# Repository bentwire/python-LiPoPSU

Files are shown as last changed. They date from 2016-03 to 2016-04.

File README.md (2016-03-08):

# python-LiPoPSU
Python drivers and sundry for my LiPo PSU design in eagle

Boards can be ordered from OSH Park

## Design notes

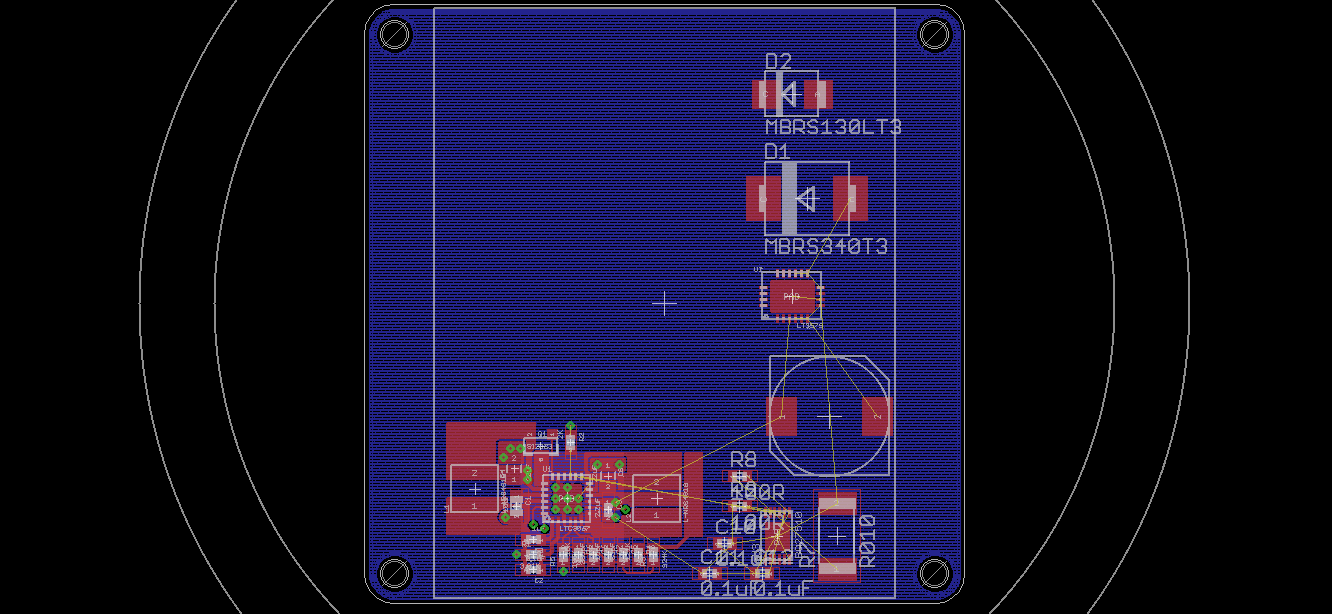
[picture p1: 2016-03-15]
eagle/LiPo-PSU/lipo.png

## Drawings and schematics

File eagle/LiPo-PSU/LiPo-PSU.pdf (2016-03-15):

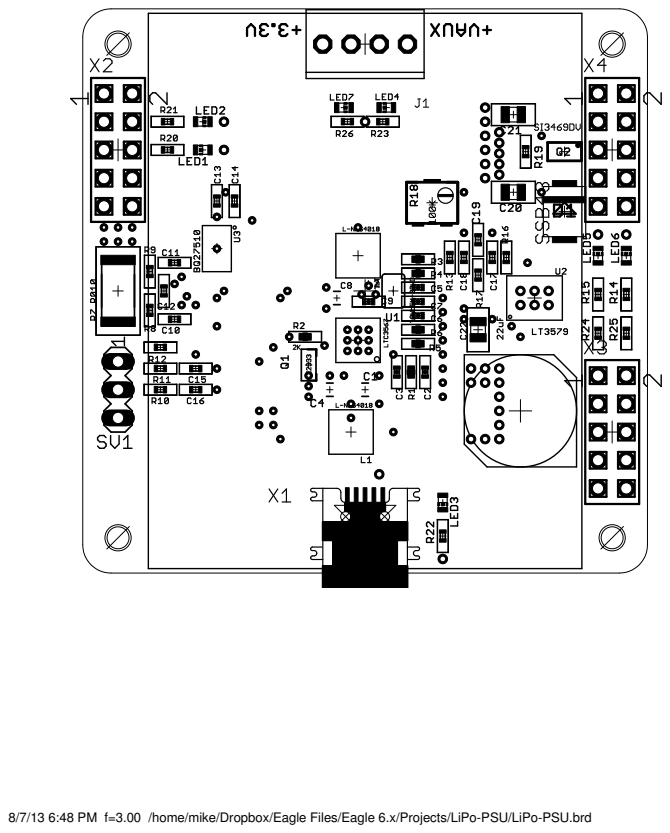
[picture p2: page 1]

8/7/13 6:48 PM f=3.00 /home/mike/Dropbox/Eagle Files/Eagle 6.x/Projects/LiPo-PSU/LiPo-PSU.brd

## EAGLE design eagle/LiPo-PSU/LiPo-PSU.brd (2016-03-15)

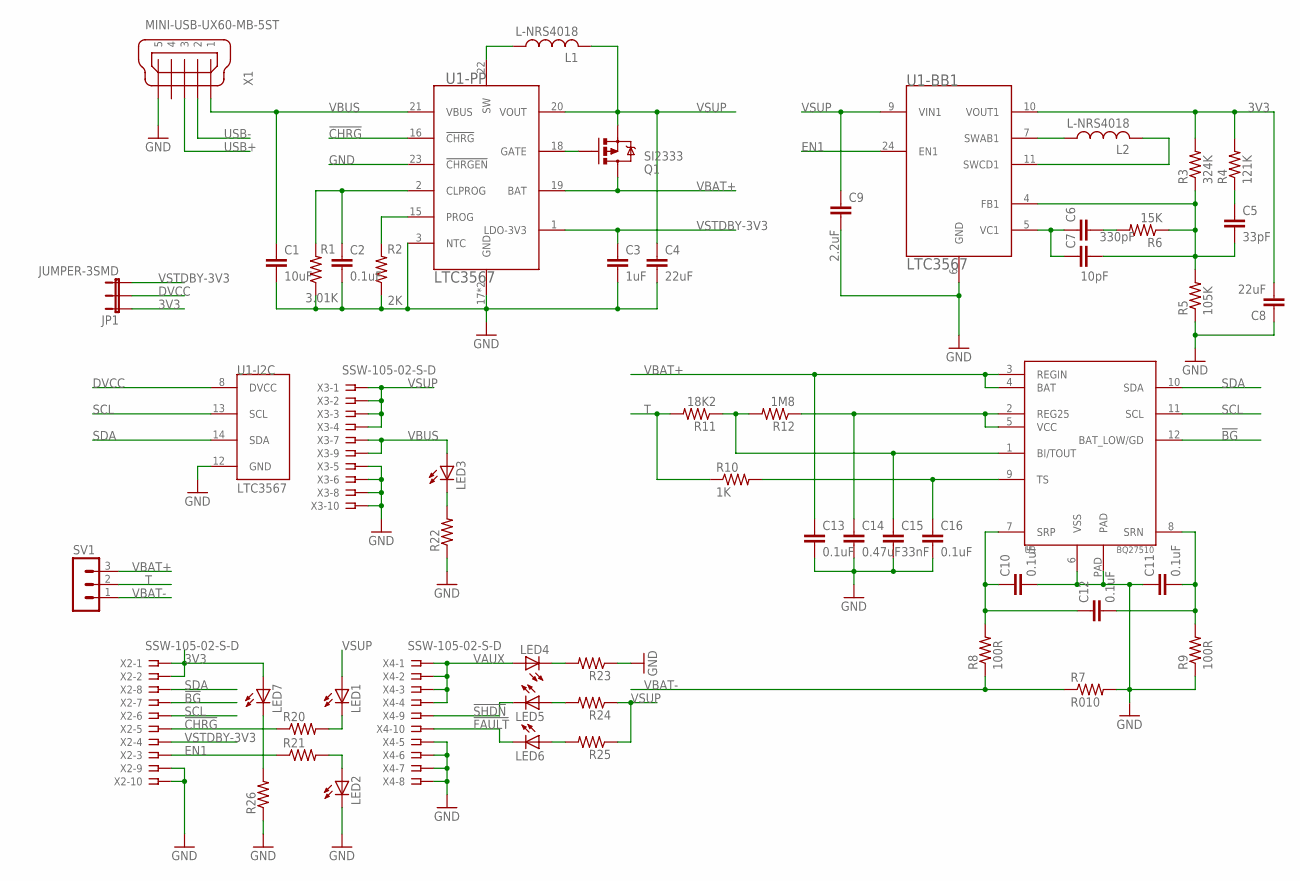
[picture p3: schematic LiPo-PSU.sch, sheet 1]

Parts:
C1: 10uF; 0805
C2: 0.1uF; 0402-CAP
C3: 1uF; 0402-CAP
C4, C8: 22uF; 0805
C5: 33pF; 0402-CAP
C6: 330pF; 0402-CAP
C7: 10pF; 0402-CAP
C9: 2.2uF; 0402-CAP
C10, C11, C12, C13, C16: 0.1uF; C0402
C14: 0.47uF; C0402
C15: 33nF; C0402
JP1: JUMPER-3SMD; SJ_3
L1, L2: L-NRS4018; NR(S)401X
LED1, LED2, LED3, LED4, LED5, LED6, LED7: LEDCHIP-LED0603; CHIP-LED0603
Q1: SI2333; SOT23-3
R1: 3.01K; 0402-RES
R2: 2K; 0402-RES
R3: 324K; 0402-RES
R4: 121K; 0402-RES
R5: 105K; 0402-RES
R6: 15K; 0402-RES
R7: R010; R2512
R8, R9: 100R; R0402
R10: 1K; R0402
R11: 18K2; R0402
R12: 1M8; R0402
R20, R21, R22, R23, R24, R25, R26: R-US_R0402; R0402
SV1: MA03-1
U1: LTC3567; QFN24-4X4(UF)
U3: BQ27510; DRZ(S-PDSO-N12)
X1: MINI-USB-UX60-MB-5ST; UX60-MB-5ST
X2, X3, X4: SSW-105-02-S-D

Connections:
3V3: C8.2, JP1.1, LED7.A, R3.2, R4.2, U1.10 (VOUT1), X2.1, X2.2; also elsewhere on the board
!BG: U3.12 (BAT_LOW/GD), X2.7
!CHRG!: R20.1, U1.16 (!CHRG!), X2.5
!FAULT: LED6.C, X4.10; also elsewhere on the board
!SHDN: LED5.C, X4.9; also elsewhere on the board
DVCC: JP1.2, U1.8 (DVCC)
EN1: R21.1, U1.24 (EN1), X2.3
GND: C1.2, C2.2, C3.2, C4.2, C8.1, C9.2, C10.2, C11.1, C13.2, C14.2, C15.2, C16.2, LED2.C, R1.1, R2.1, R5.1, R7.2, R9.1, R22.1, R23.1, R26.1, U1.3 (NTC), U1.6 (GND), U1.12 (GND), U1.17 (GND), U1.23 (!CHRGEN!), U1.PAD (GND), U3.6 (VSS), U3.PAD, X1.5, X2.9, X2.10, X3.5, X3.6, X3.8, X3.10, X4.5, X4.6, X4.7, X4.8; also elsewhere on the board
unnamed: L1.1, U1.22 (SW)
unnamed: C5.2, C7.2, R3.1, R5.2, R6.1, U1.4 (FB1)
unnamed: Q1.1 (G), U1.18 (GATE)
unnamed: L2.1, U1.7 (SWAB1)
unnamed: L2.2, U1.11 (SWCD1)
unnamed: C5.1, R4.1
unnamed: C15.1, R11.1, R12.2, U3.1 (BI/TOUT)
unnamed: C6.2, R6.2
unnamed: C6.1, C7.1, U1.5 (VC1)
unnamed: C2.1, R1.2, U1.2 (CLPROG)
unnamed: R2.2, U1.15 (PROG)
unnamed: LED1.C, R20.2
unnamed: C14.1, R12.1, U3.2 (REG25), U3.5 (VCC)
unnamed: LED2.A, R21.2
unnamed: LED3.C, R22.2
unnamed: LED5.A, R24.2
unnamed: LED6.A, R25.2
unnamed: LED4.C, R23.2
unnamed: LED7.C, R26.2
SCL: U1.13 (SCL), U3.11 (SCL), X2.6
SDA: U1.14 (SDA), U3.10 (SDA), X2.8
SRN: C11.2, C12.2, R9.2, U3.8 (SRN)
SRP: C10.1, C12.1, R8.2, U3.7 (SRP)
T: R10.1, R11.2, SV1.2
TIN: C16.1, R10.2, U3.9 (TS)
USB+: X1.3
USB-: X1.2
VAUX: LED4.A, X4.1, X4.2, X4.3, X4.4; also elsewhere on the board
VBAT+: C13.1, Q1.3 (D), SV1.3, U1.19 (BAT), U3.3 (REGIN), U3.4 (BAT)
VBAT-: R7.1, R8.1, SV1.1
VBUS: C1.1, LED3.A, U1.21 (VBUS), X1.1, X3.7, X3.9
VSTDBY-3V3: C3.1, JP1.3, U1.1 (LDO-3V3), X2.4
VSUP: C4.1, C9.1, L1.2, LED1.A, Q1.2 (S), R24.1, R25.1, U1.9 (VIN1), U1.20 (VOUT), X3.1, X3.2, X3.3, X3.4; also elsewhere on the board

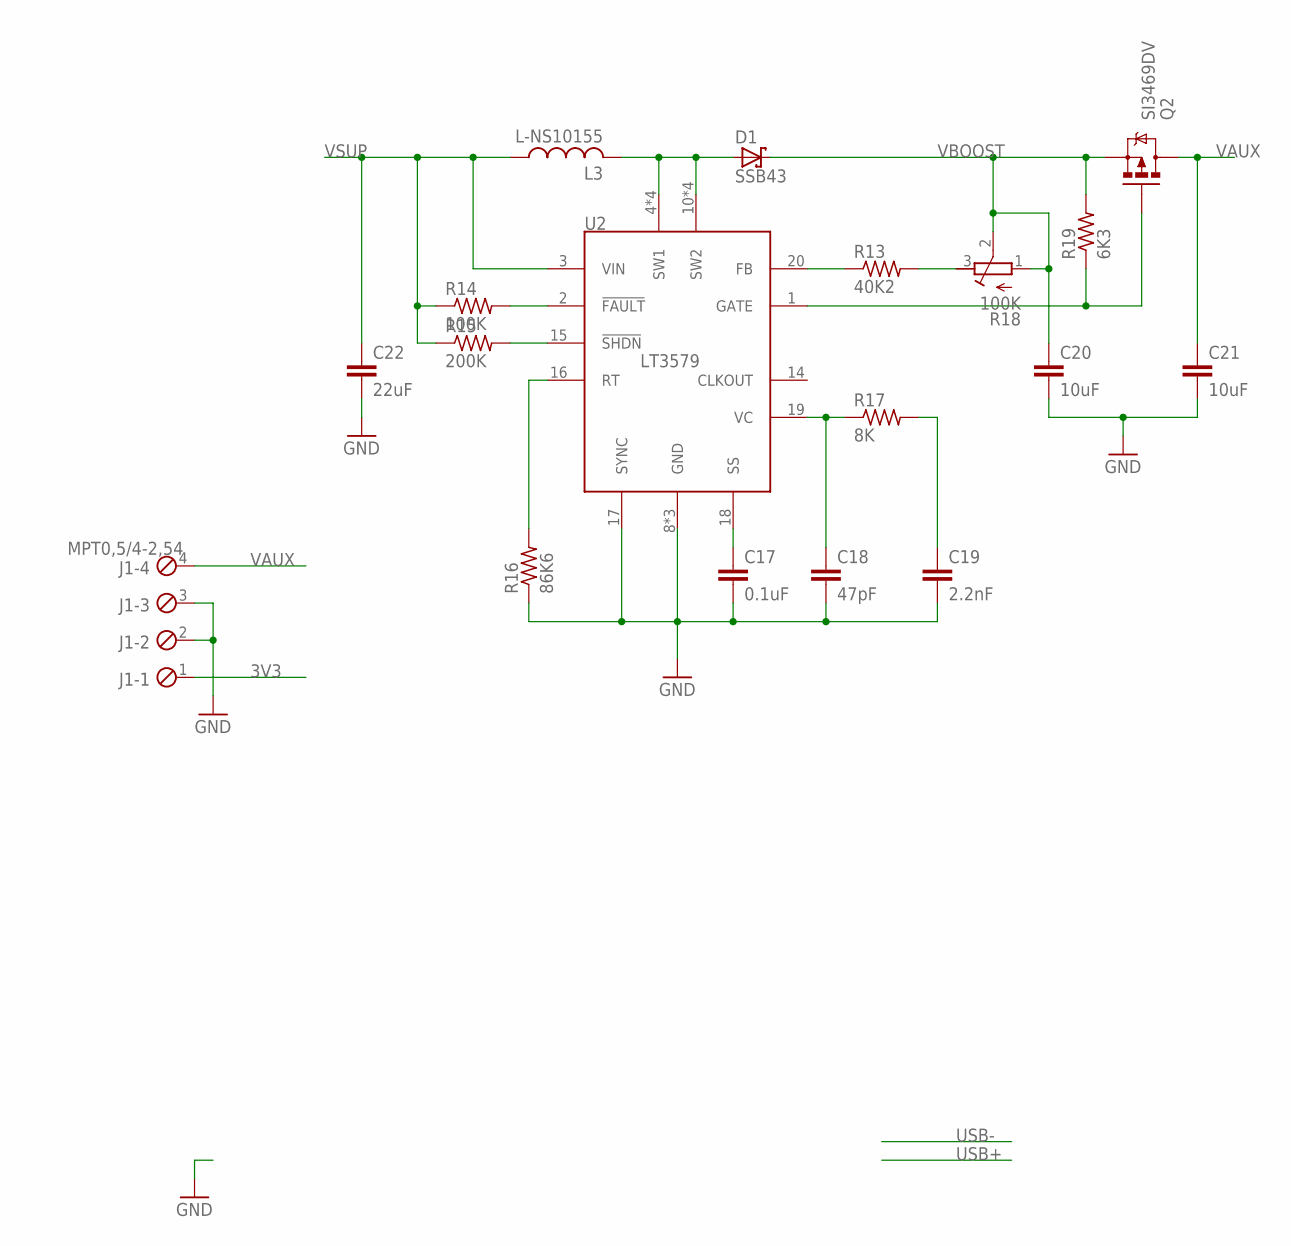
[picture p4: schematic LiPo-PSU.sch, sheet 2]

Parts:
C17: 0.1uF; C0402
C18: 47pF; C0402
C19: 2.2nF; C0402
C20, C21: 10uF; C0805
C22: 22uF; C0805
D1: SSB43; SMB
J1: MPT0,5/4-2,54
L3: L-NS10155; NS10155
Q2: SI3469DV; TSOP-6
R13: 40K2; R0402
R14: 100K; R0402
R15: 200K; R0402
R16: 86K6; R0402
R17: 8K; R0402
R18: 100K; RTRIM3214W
R19: 6K3; R0402
U2: LT3579; QFN20-4X5(UFD)

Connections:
3V3: J1.1; also elsewhere on the board
!FAULT: R14.2, U2.2 (!FAULT!); also elsewhere on the board
!SHDN: R15.2, U2.15 (!SHDN!); also elsewhere on the board
BOOST-FB: R13.1, U2.20 (FB)
GATE: Q2.3 (G), R19.1, U2.1 (GATE)
GND: C17.2, C18.2, C19.2, C20.2, C21.2, C22.2, J1.2, J1.3, R16.1, U2.8 (GND), U2.9 (GND), U2.17 (SYNC), U2.PAD (GND); also elsewhere on the board
unnamed: D1.A, L3.2, U2.4 (SW1), U2.5 (SW1), U2.6 (SW1), U2.7 (SW1), U2.10 (SW2), U2.11 (SW2), U2.12 (SW2), U2.13 (SW2)
unnamed: R13.2, R18.3 (A)
unnamed: R16.2, U2.16 (RT)
unnamed: C18.1, R17.1, U2.19 (VC)
unnamed: C19.1, R17.2
unnamed: C17.1, U2.18 (SS)
VAUX: C21.1, J1.4, Q2.1 (D), Q2.2 (D), Q2.5 (D), Q2.6 (D); also elsewhere on the board
VBOOST: C20.1, D1.C, Q2.4 (S), R18.1 (E), R18.2 (S), R19.2
VSUP: C22.1, L3.1, R14.1, R15.1, U2.3 (VIN); also elsewhere on the board

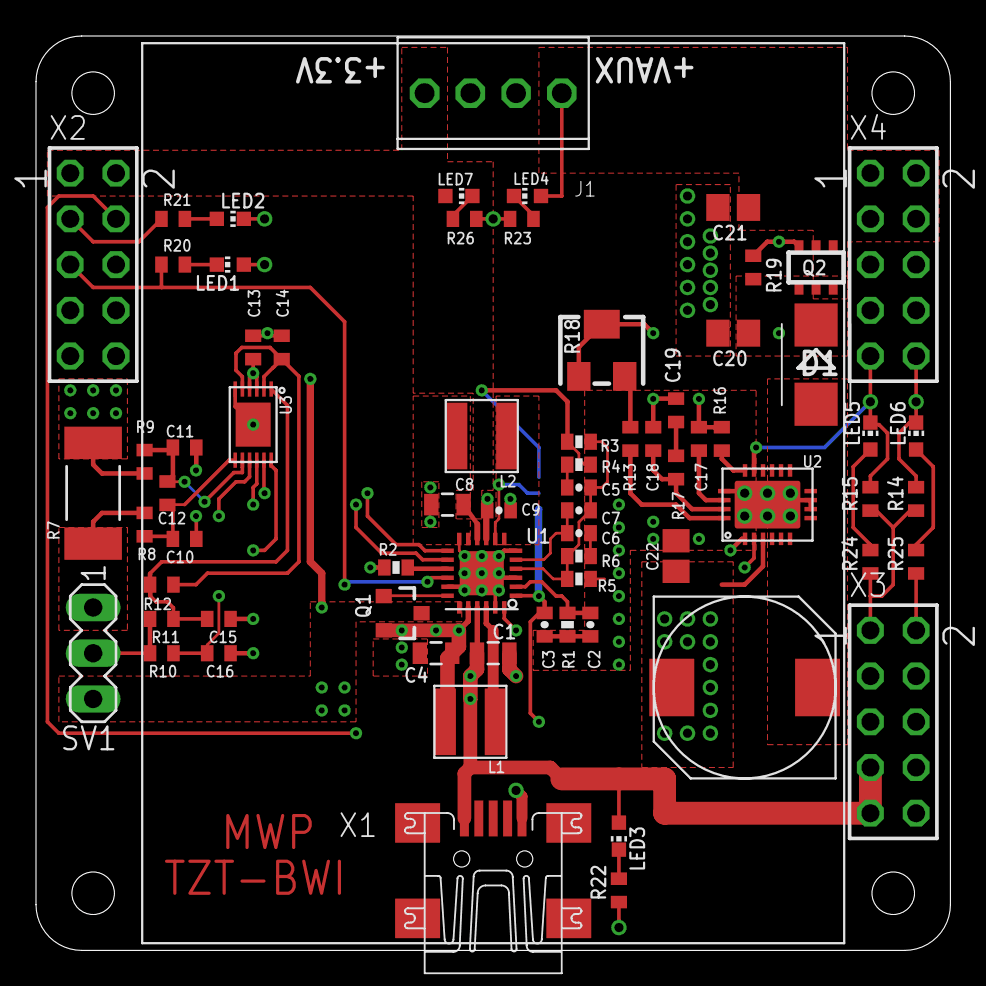
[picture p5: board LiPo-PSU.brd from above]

Board: 4 copper layers, 50.8 x 50.8 mm, 72 parts (1 on the bottom side), 48 nets.

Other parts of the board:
U$1: LP503950

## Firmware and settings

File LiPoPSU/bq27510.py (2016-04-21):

import time
import logging

log = logging.getLogger(__name__)


class bq27510(object):
    CNTL    = 0x00 # This and AR are the only R/W regs.
    AR      = 0x02
    ARTTE   = 0x04 # From here down the registers are RO.
    TEMP    = 0x06
    VOLT    = 0x08
    FLAGS   = 0x0a
    NAC     = 0x0c
    FAC     = 0x0e
    RM      = 0x10
    FCC     = 0x12
    AI      = 0x14
    TTE     = 0x16
    TTF     = 0x18
    SI      = 0x1a
    STTE    = 0x1c
    MLI     = 0x1e
    MLTTE   = 0x20
    AE      = 0x22
    AP      = 0x24
    TTECP   = 0x26
    RSVD    = 0x28
    CC      = 0x2a
    SOC     = 0x2c

    ADDRESS = 0x55

    def __init__(self, bus, retries = 5):
        self.bus     = bus
        self.retries = retries

    def readReg(self, reg):
        for retry in range(self.retries):
            try:
                return self.bus.read_word_data(bq27510.ADDRESS, reg)
            except Exception as e:
                log.error("Exception during read: %s" % (e))
                time.sleep(0.1)
        else:
            raise Exception("Too many retries on READ.")

    @property
    def Control(self):
        return self.readReg(bq27510.CNTL)

    @Control.setter
    def Control(self, val):
        return self.writeReg(bq27510.CNTL)

    @property
    def Temperature(self):
        return self.readReg(bq27510.TEMP)

    @property
    def Voltage(self):
        voltage = self.readReg(bq27510.VOLT)
        return float(voltage)/1000

    @property
    def Flags(self):
        return self.readReg(bq27510.FLAGS)

    @property
    def NominalAvailableCapacity(self):
        cap = self.readReg(bq27510.NAC)
        return float(cap)/1000

    @property
    def FullAvailableCapacity(self):
        cap = self.readReg(bq27510.FAC)
        return float(cap)/1000

    @property
    def RemainingCapacity(self):
        cap = self.readReg(bq27510.RM)
        return float(cap)/1000

    @property
    def FullChargeCapacity(self):
        cap = self.readReg(bq27510.FCC)
        return float(cap)/1000

    @property
    def AverageCurrent(self):
        current = self.readReg(bq27510.AI)
        if current > 32767:
            current -= 65536
        return float(current)/1000

    @property
    def TimeToEmpty(self):
        return self.readReg(bq27510.TTE)

    @property
    def TimeToFull(self):
        return self.readReg(bq27510.TTF)

    @property
    def StandbyCurrent(self):
        i = self.readReg(bq27510.SI)
        return float(i)/1000

    @property
    def StandbyTimeToEmpty(self):
        return self.readReg(bq27510.STTE)

    @property
    def MaxLoadCurrent(self):
        i = self.readReg(bq27510.MLI)
        return float(i)/1000

    @property
    def MaxLoadTimeToEmpty(self):
        return self.readReg(bq27510.MLTTE)

    @property
    def AvailableEnergy(self):
        ae = self.readReg(bq27510.AE)
        return float(ae)/1000

    @property
    def AveragePower(self):
        ap = self.readReg(bq27510.AP)
        return float(ap)/1000

    @property
    def TTEatConstantPower(self):
        return self.readReg(bq27510.TTECP)

    @property
    def CycleCount(self):
        return self.readReg(bq27510.CC)

    @property
    def StateOfCharge(self):
        return self.readReg(bq27510.SOC)

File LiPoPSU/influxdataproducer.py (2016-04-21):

#!/usr/bin/env python

"""Generate time series data for influxdb.

Usage:
    influx-data-producer [--host=<dbhost>] [--port=<dbport>] [--ssl] [--dbname=<name>] [--dbpass=<passwd>] [--dbuser=<user>] [--loglevel=<LEVEL>]

Options:
    -h, --help  Show this screen.
    --host=<dbhost>  The influxdb host [default: localhost]
    --port=<dbport>  The influxdb port [default: 8086]
    --ssl            Enable TLS support
    --loglevel=<LEVEL>  The log level to report at. [default: INFO]
"""

# from datetime import timedelta, datetime;
# import os
import time
from influxdb import InfluxDBClient
from LiPoPSU import bq27510
from docopt import docopt

import logging

try:
    import smbus
except:
    print("Demo mode activated")


def battery_data(battery):
    tte = battery.TimeToEmpty
    ttf = battery.TimeToFull

    soc = battery.StateOfCharge
    v   = battery.Voltage
    ac  = battery.AverageCurrent
    nac = battery.NominalAvailableCapacity
    fac = battery.FullAvailableCapacity
    fcc = battery.FullChargeCapacity
    rc  = battery.RemainingCapacity

    sc      = battery.StandbyCurrent
    stte    = battery.StandbyTimeToEmpty
    mlc     = battery.MaxLoadCurrent
    mltte   = battery.MaxLoadTimeToEmpty

    ae      = battery.AvailableEnergy
    ap      = battery.AveragePower
    ttecp   = battery.TTEatConstantPower

    cc      = battery.CycleCount

    temp    = battery.Temperature

#    print("SOC: %3.2d%%\tV: %4.3fV\tI: %4.3fA\tTTE: %s\tTTF: %s\tNAC: %4.3fAh\tFAC: %4.3fAh\tFCC: %4.3fAh\tRC: %4.3fAh" % (soc, v, ac, tte, ttf, nac, fac, fcc, rc))
    return [
        {
            "measurement": "battery_status",
            "fields": {
                "StateOfCharge": soc,
                "Voltage": v,
                "AverageCurrent": ac,
                "TimeToEmpty": tte,
                "TimeToFull": ttf,
                "NominalAvailableCapacity": nac,
                "FullAvailableCapacity": fac,
                "FullChargeCapacity": fcc,
                "RemaningCapacity": rc,
                "StandbyCurrent": sc,
                "StandbyTimeToEmpty": stte,
                "MaxLoadCurrent": mlc,
                "MaxLoadTimeToEmpty": mltte,
                "AvailableEnergy": ae,
                "AveragePower": ap,
                "TTEatConstantPower": ttecp,
                "CycleCount": cc,
                "Temperature": temp
            },
            'name': 'Battery Status',
        }
    ]


def run():
    arguments = docopt(__doc__, version='0.1.1')

    host     = arguments['--host']
    port     = arguments['--port']
    ssl      = arguments['--ssl']
    database = arguments['--dbname']
    password = arguments['--dbpass']
    user     = arguments['--dbuser']
    loglevel = arguments['--loglevel']
    log      = logging.getLogger('influx-data-producer')

    log.setLevel(getattr(logging, loglevel.upper()))
    logging.basicConfig(level=getattr(logging, loglevel.upper()))

    log.debug("Initializing influxDB connection")
    influx = InfluxDBClient(host, port, database, password, user, ssl=ssl, verify_ssl=ssl)

    log.debug("Initializing SMBus connection")
    try:
        bus = smbus.SMBus(1)
    except Exception as e:
        bus = None

    log.debug("Initializing battery object")
    battery = bq27510.bq27510(bus)

    while True:
        try:
            data = battery_data(battery)
            log.debug("Gathered data points.")
            log.debug(data)
            influx.write_points(data)
        except Exception as e:
            log.warning("Caught exception while uploading data point: '%s'" % (e))
            continue
        time.sleep(5)

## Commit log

2016-03-08 Link to boards.
2016-03-15 Added eagle CAD files.
    [LiPo-PSU.brd, LiPo-PSU.sch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]
2016-03-29 Removed debug print.
2016-04-09 Add temperature.

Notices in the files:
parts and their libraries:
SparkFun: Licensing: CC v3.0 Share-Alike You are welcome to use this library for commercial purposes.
